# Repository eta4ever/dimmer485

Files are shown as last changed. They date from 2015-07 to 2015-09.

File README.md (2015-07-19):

Домашняя автоматизация. Пока что работаю над светом. 
Блок энкодера, блок драйвера-диммера, код для центрального управлятора. 
Связь по RS-485, свой простейший протокол.

hardware - актуальная папка для железа. Схемы (Eagle), разводки (SL6)
avr-dimmer, avr-encoder - проекты Eclipse+AVR для контроллеров. Надо потом свести в одну прошивку.
host - софт хоста (мастера сети), Python

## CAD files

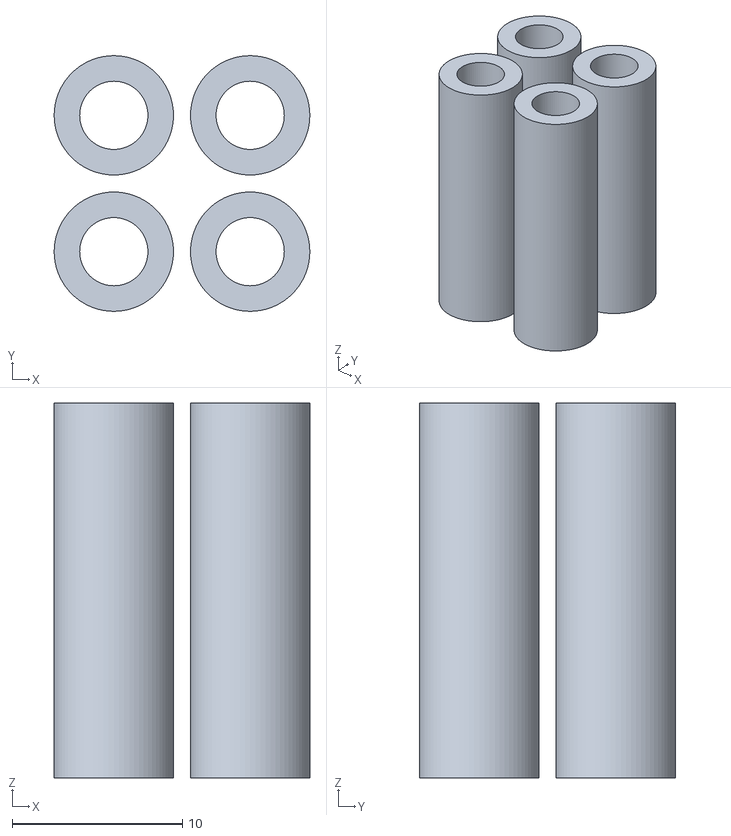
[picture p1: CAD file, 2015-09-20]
hardware/3d/vtoolkee.stl
15.0 x 15.0 x 22.0

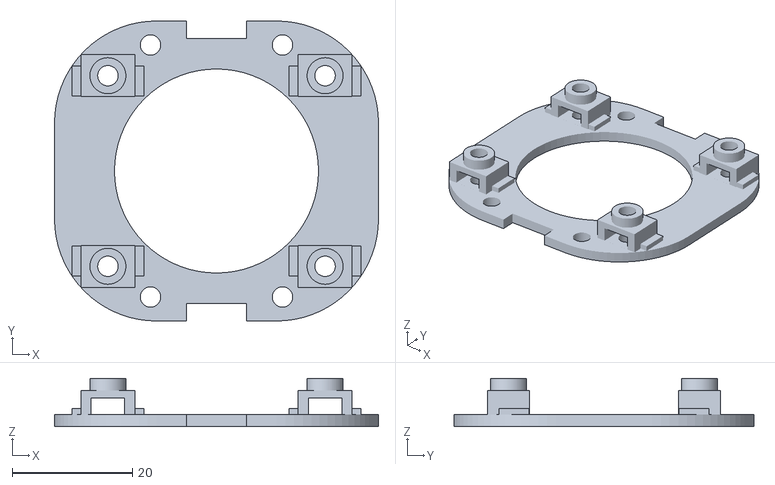
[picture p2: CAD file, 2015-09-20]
hardware/3d/box_insert.stl
54.0 x 50.0 x 8.00

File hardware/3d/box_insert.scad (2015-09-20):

$fa=5; $fs=0.1;

difference(){

    union()
    {
        // платформа
        
        hull(){
            translate([-10, 8, -1]) cylinder(r=17, h=2, center=true);
            translate([10, 8, -1]) cylinder(r=17, h=2, center=true);
            translate([10, -8, -1]) cylinder(r=17, h=2, center=true);
            translate([-10, -8, -1]) cylinder(r=17, h=2, center=true);
        }
        
        // упоры
        translate([18.1, 15.88, 5]) cylinder(r=3, h=2, center=true);
        translate([-18.1, 15.88, 5]) cylinder(r=3, h=2, center=true);
        translate([18.1, -15.88, 5]) cylinder(r=3, h=2, center=true);
        translate([-18.1, -15.88, 5]) cylinder(r=3, h=2, center=true);
        
        translate([18.1, 15.88, 2]) cube([9,7,4], center=true);
        translate([18.1, -15.88, 2]) cube([9,7,4], center=true);
        translate([-18.1, 15.88, 2]) cube([9,7,4], center=true);
        translate([-18.1, -15.88, 2]) cube([9,7,4], center=true);
        
        translate([18.1, 15, 0.5]) cube([12,5,1], center=true);
        translate([18.1, -15, 0.5]) cube([12,5,1], center=true);
        translate([-18.1, 15, 0.5]) cube([12,5,1], center=true);
        translate([-18.1, -15, 0.5]) cube([12,5,1], center=true);
        
    }
    
    union()
    {
        // отверстия под плату
        translate([18.1, 15.88, 2]) cylinder(r=1.7, h=8.01, center=true);
        translate([-18.1, 15.88, 2]) cylinder(r=1.7, h=8.01, center=true);
        translate([18.1, -15.88, 2]) cylinder(r=1.7, h=8.01, center=true);
        translate([-18.1, -15.88, 2]) cylinder(r=1.7, h=8.01, center=true);
        
        // прорези под гайки
        translate([18.1, 15.88, 1.36]) cube([5.6, 7.01, 2.7], center=true);
        translate([-18.1, 15.88, 1.36]) cube([5.6, 7.01, 2.7], center=true);
        translate([18.1, -15.88, 1.36]) cube([5.6, 7.01, 2.7], center=true);
        translate([-18.1, -15.88, 1.36]) cube([5.6, 7.01, 2.7], center=true);
        
        // крепежные отверстия
        translate([-11, 21 , -1]) cylinder(r=1.7, h=2.01, center=true);
        translate([11, 21 , -1]) cylinder(r=1.7, h=2.01, center=true);
        translate([11, -21 , -1]) cylinder(r=1.7, h=2.01, center=true);
        translate([-11, -21 , -1]) cylinder(r=1.7, h=2.01, center=true);
        
        // прорези между крепежными отверстиями
        translate([0, 23.6, -1]) cube([10, 3, 2.01], center=true);
        translate([0, -23.6, -1]) cube([10, 3, 2.01], center=true);
        
        // центральное отверстие
        translate([0, 0, -1]) cylinder(r=17, h=2.01, center=true);
      
        
    }
    
}

//втулки высокие
//
//    difference()
//        {
//            translate([5,5,9]) cylinder(r=3, h=22, center=true);
//            translate([5,5,9]) cylinder(r=1.7, h=22.01, center=true);
//        } 
//      
//    difference()
//        {
//            translate([5,-5,9]) cylinder(r=3, h=22, center=true);
//            translate([5,-5,9]) cylinder(r=1.7, h=22.01, center=true);
//        }     
//        
//    difference()
//        {
//            translate([-5,5,9]) cylinder(r=3, h=22, center=true);
//            translate([-5,5,9]) cylinder(r=1.7, h=22.01, center=true);
//        }   
//        
//    difference()
//        {
//            translate([-5,-5,9]) cylinder(r=3, h=22, center=true);
//            translate([-5,-5,9]) cylinder(r=1.7, h=22.01, center=true);
//        }   

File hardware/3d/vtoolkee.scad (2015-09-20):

$fa=5; $fs=0.1;

//втулки высокие

    difference()
        {
            translate([4,4,9]) cylinder(r=3.5, h=22, center=true);
            translate([4,4,9]) cylinder(r=2, h=22.01, center=true);
        } 
      
    difference()
        {
            translate([4,-4,9]) cylinder(r=3.5, h=22, center=true);
            translate([4,-4,9]) cylinder(r=2, h=22.01, center=true);
        }     
        
    difference()
        {
            translate([-4,4,9]) cylinder(r=3.5, h=22, center=true);
            translate([-4,4,9]) cylinder(r=2, h=22.01, center=true);
        }   
        
    difference()
        {
            translate([-4,-4,9]) cylinder(r=3.5, h=22, center=true);
            translate([-4,-4,9]) cylinder(r=2, h=22.01, center=true);
        }   

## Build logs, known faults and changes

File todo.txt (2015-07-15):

Сделать счетчик ошибок обращения, по которому передергивается conn

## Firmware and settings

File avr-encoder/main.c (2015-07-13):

#define F_CPU 8000000UL // 8 МГц от встроенного генератора
#include <avr/io.h> // ввод-вывод
#include <util/delay.h> // задержки
#include <avr/interrupt.h> // прерывания

// адрес мастера сети
#define MASTER 1

// команды
#define READ_REG 10
#define WRITE_REG 20
#define CHANGE_ADDR 30

#define REGS_TO_MASTER 50 // код команды при отправке регистров мастеру

#define MIN_LEVEL 20 // минимальный уровень яркости

// глобальная переменная пакета данных
unsigned char packet[5];

// регистры данных
// для энкодера с кнопкой первый (старший) байт хранит 0-255 значение,
// второй 0 или 255 соотв. выкл-вкл.
unsigned char data[2] = {0, 0};

// адрес этого устройства
// алярма: 255 не используем, он пишется в пакет при таймауте
unsigned char address = 50;

// флаг таймаута приема
unsigned char timeout = 0;

// флаг разрешения проверки энкодера
unsigned char encoder_enabled = 1;

// текущее состояние энкодера и кнопки
unsigned char encoder_state = 0;
unsigned char button_state = 0;


// Инициализация
void setup(void){
	// режим портов
	DDRD = 0b00000100; // PD2 = 1 - запись MAX485
	DDRC = 0b00000000; // PC0 вход кнопки, PC1-2 - энкодера
	PORTC = 0b11111111; // подключение подтягивающих резисторов

	// настройка последовательного интерфейса

	// установка стандартного режима 8N1
	UCSR0C=(1<<USBS0)|(1<<UCSZ01)|(1<<UCSZ00);

	// установка скорости.
	// тут курим AVR Baudrate Calculator, почему
	// не все скорости одинаково полезны
	// UBRR0L=25; // 19200
	UBRR0L=12; // 38400
	UBRR0H=0;

	// разрешение приема и передачи по UART
	// RXENable, TXENable в регистре UCSRB
	//UCSR0B=(1<<RXEN0)|(1<<TXEN0);

	// разрешение прерывания по переполнению timer0
	TIMSK0 = (1<<TOIE0);

	// разрешение прерывания по переполнению timer2
	TIMSK2 = (1<<TOIE2);

	// запуск timer2 с делителем 32, дает примерно 1 кГц частоту
	TCNT2 = 0;
	TCCR2B = (1<<CS21) | (1<<CS20);

	// глобальное разрешение прерываний
	sei();
}

// Разрешение опроса энкодера
void encoder_enable(unsigned char val){

	if (val == 0) {
		encoder_enabled = 0;
	}
	else {
		encoder_enabled = 1;
	}
}

// опрос энкодера
void encoder_scan(void){

	// текущее состояние - биты 1 и 2 порта C
	// оно может быть 0 (00), 1 (01), 2(10), 3 (11)
	unsigned char new_encoder_state = (PINC & 0b00000110) >> 1;

	// последовательность увеличения: 00-10-11-01-...
	// уменьшения 00-01-11-10-...

	switch (encoder_state){

		case 3:
		{
			// 11 -> 01 +
			if ((new_encoder_state == 1) && (data[0] != 255)) data[0]++;
			// 11 -> 10 -
			if ((new_encoder_state == 2) && (data[0] != MIN_LEVEL)) data[0]--;
			break;
		}

		case 2:
		{
			// 10 -> 11 +
			if ((new_encoder_state == 3) && (data[0] != 255)) data[0]++;
			// 10 -> 00 -
			if ((new_encoder_state == 0) & (data[0] != MIN_LEVEL)) data[0]--;
			break;
		}

		case 1:
		{
			// 01 -> 00 +
			if ((new_encoder_state == 0) && (data[0] != 255)) data[0]++;
			// 01 -> 11 -
			if ((new_encoder_state == 3) && (data[0] != MIN_LEVEL)) data[0]--;
			break;
		}

		case 0:
		{
			// 00 -> 10 +
			if ((new_encoder_state == 2) && (data[0] != 255)) data[0]++;
			// 00 -> 01 -
			if ((new_encoder_state == 1) && (data[0] != MIN_LEVEL)) data[0]--;
			break;
		}

	}

	// опрос кнопки, отрабатывается нажатие (1-0)
	unsigned char new_button_state = PINC & 0b00000001;
	if ((button_state == 1) && (new_button_state == 0)) data[1] = !data[1];

	encoder_state = new_encoder_state; //фиксация состояния энкодера
	button_state = new_button_state; // фиксация состояния кнопки
}

// прерывание по таймеру0 - установка флаг таймаута приема
ISR(TIMER0_OVF_vect){
	timeout = 1;
}

// прерывание по таймеру1 - опрос энкодера, если разрешено
ISR(TIMER2_OVF_vect){
	if (encoder_enabled) encoder_scan();
}

// вычисление контрольной суммы пакета
unsigned char checksum(){

	unsigned int sum = 0;
	for (unsigned char counter = 0; counter < 4; counter++){
		sum += packet[counter];
	}

	return sum % 256;
}

// прием 5 байт по UART
// возвращает 0xFF при успешном приеме
// 0x00 при таймауте приема, несовпадении контрольной суммы
// или несоответствии адреса
unsigned char receive_packet(void){

	PORTD &= 0b11111011; // включение max485 на прием
	_delay_us(1); // задержка на установление режима
	UCSR0B=(1<<RXEN0); // разрешение приема по UART

	// получение первого байта пакета
	while(!(UCSR0A & (1<<RXC0)));
	packet[0] = UDR0;

	// как только первый байт получен,
	// запретить опрос энкодера и запустить таймер

	encoder_enable(0);

	// запуск timer0
	timeout = 0; // сброс флага переполнения таймера
	TCNT0 = 0; // обнуление счетчика таймера
	TCCR0B = (1<<CS02) | (1<<CS00); // запуск с делителем 1024

	// получение еще четырех байт пакета
	for (unsigned char counter=1; counter<5; counter++)
	{
		// ожидание приемника, если таймаут -
		// запись FF во все поля пакета и выдача результата 0x00
		while(!(UCSR0A & (1<<RXC0))) {

			if (timeout == 1){
				TCCR0B = 0; // остановка таймера
				encoder_enable(1); //разрешение опроса энкодера
				for (unsigned char counter1=0; counter1<5; counter1++){ packet[counter1] = 0xFF; };
				return 0x00;
			}
		}

		// получение байта
		packet[counter] = UDR0;
	}

	TCCR0B = 0; // остановка таймера
	encoder_enable(1); // разрешение опроса энкодера
	UCSR0B=0; // запрет UART

	// проверка контрольной суммы. Не совпадает - вернуть 0x00
	unsigned char packet_checksum = checksum();
	if (packet[4] != packet_checksum) {return 0x00;};

	// проверка адреса приемника. Не совпадает - вернуть 0x00
	if (packet[0] != address) {return 0x00;};

	return 0xFF; // удачное завершение
}

// отправка пакета
void send_packet(void){

	unsigned char packet_checksum = checksum(); // вычисление контрольной суммы пакета
	packet[4] = packet_checksum;

	PORTD |= 0b00000100; // включение max485 на передачу
	_delay_ms(1); // задержка на установление режима
	UCSR0B=(1<<TXEN0); // разрешение передачи

	// запрет опроса энкодера
	encoder_enable(0);

	for (unsigned char counter=0; counter<5; counter++)
	{
		// ожидание освобождения буфера
		while(!(UCSR0A & (1<<UDRE0)));

		// отправка байта
  		UDR0 = packet[counter];
 	}

	encoder_enable(1); // разрешение опроса энкодера
	UCSR0B = 0; // запрет UART
}

// отправка регистров мастеру
// используется и как подтверждение приема команды
void send_registers(void){
	packet[0] = MASTER;
	packet[1] = REGS_TO_MASTER;
	packet[2] = data[0];
	packet[3] = data[1];

	send_packet();
}

// обработка пакета, отработка принятых команд
void process_packet(void){

	switch (packet[1]){

		case READ_REG: {
			send_registers(); // отправка регистров
			break;
		}

		case WRITE_REG:{	// запись регистров
			data[0] = packet[2];
			data[1] = packet[3];
			if (data[0] < MIN_LEVEL) data[0] = MIN_LEVEL; // проверка на минимальный уровень
			send_registers();
			break;
		}

		case CHANGE_ADDR:{ // смена адреса
			address = packet[2];
			send_registers();
			break;
		}
	}
}

// прием пакета, если пакет понравился - обработать его
int main (void){

	setup(); // инициализация всего
	unsigned char rx_result; // результат приема пакета

	while(1){

		rx_result = receive_packet();
		_delay_us(1);

		if (rx_result) {
			process_packet();
		}
		_delay_ms(1);
	}

	return 0;
}

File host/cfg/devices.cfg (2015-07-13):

[Encoder 1]
	address = 50
	name = encoder1
	type = encoder
	controls = led1
	priority = 30
	reg1 = 10
	reg2 = 1
	enabled = 1

[Override 1]
	name = override1
	type = virtual
	controls = led1
	priority = 5
	reg1 = 200
	reg2 = 1
	enabled = 0

[Device2]
	address = 60
	name = led1
	type = pwm
	reg1 = 0
	reg2 = 0
	enabled = 1

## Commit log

2015-06-28 intial commit - mega8 dimmer control
    mega8 + max485 control board
    [encoder.sch]
2015-07-03 correct comm code avr, OOP host code
    [comm485.py, device485.py, host.py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]
2015-07-03 config file, initial registers setup
    [devices.cfg]
2015-07-03 led driver schematic
    [led driver.sch]
2015-07-03 led driver sch and pcb
    [led driver.sch]
2015-07-03 cfg advance
    config in separate folder, additional cfg for COM port
    [connection.cfg, devices.cfg]
2015-07-06 led driver corrected, led driver test code
    [led driver.sch]
2015-07-06 functional led driver
    [devices.cfg]
2015-07-08 switched to Eclipse
    Swtiched to Eclipse with AVR plugin
    [connection.cfg]
2015-07-09 testing timer object
    [timers.cfg]
2015-07-11 Отладка
    Заменен адаптер (была проблема с долгим переключением DTR, сейчас FT232
    с 13-м пином), отладка (проблемы с приемом на ПК)
    [connection.cfg]
2015-07-12 Допиливание железа
    Подтяжки TX на Vcc, забытый резистор на верхнем транзисторе в драйвере,
    конденсаторы на питание МК, подписи элементов в разводке
    [encoder.sch, led driver.sch]
2015-07-12 реализация приоритетов
    [devices.cfg]
2015-07-13 encoder portc setup fixed
    [main.c]
2015-07-13 изменение разводки под энкодер
    энкодер на землю, подтягивающие резисторы к плюсу
    [devices.cfg, encoder.sch]
2015-07-13 минимальный уровень яркости
2015-07-15 работа над бутербродной версией
    [encoder.sch, led driver.sch]
2015-07-15 работа над бутербродом
    [encoder.gbl, encoder.gbo, encoder.gbs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]
2015-07-15 коррекция гербера
    [main.gto]
2015-07-15 бутерброд - основная плата и драйвер
    [led driver.sch]
2015-07-19 реорганизация
    Разводка дочерней платы энкодера (теперь три платы в одном файле),
    актуальная папка для железа - hardware
    [encoder.sch, led driver.sch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]
2015-07-21 энкодер отцентрирован
2015-07-27 rj-45 for mcu board
2015-09-18 гербарий
    [dmr_drvr.gbl, dmr_drvr.gbo, dmr_drvr.gbs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]
2015-09-18 box insert
    [box_insert.scad, box_insert.stl]
2015-09-18 фихед
    [box_insert.scad, box_insert.stl]
2015-09-19 mod for real Schneider box
    [box_insert.scad, box_insert.stl]
2015-09-19 mod for real box
    [box_insert.scad, box_insert.stl]
2015-09-20 усиленные упоры
    [box_insert.scad, box_insert.stl]
2015-09-20 втулкии
    [vtoolkee.scad, vtoolkee.stl]
2015-09-20 увеличен диаметр кхтулок
    [vtoolkee.scad, vtoolkee.stl]
